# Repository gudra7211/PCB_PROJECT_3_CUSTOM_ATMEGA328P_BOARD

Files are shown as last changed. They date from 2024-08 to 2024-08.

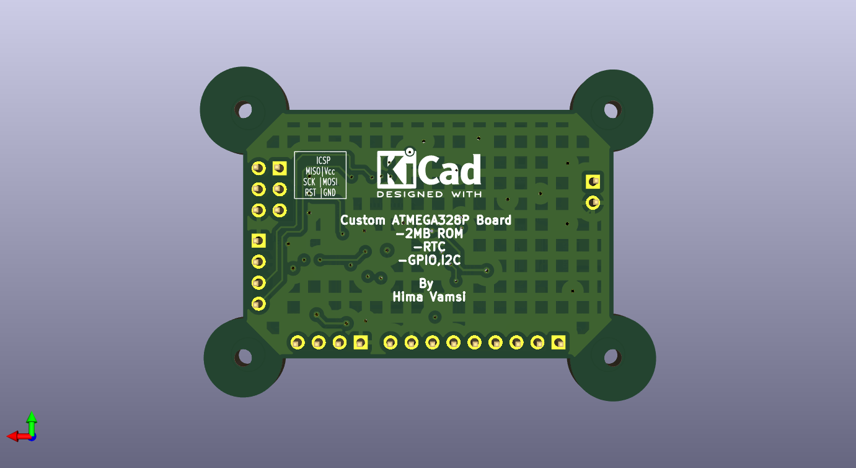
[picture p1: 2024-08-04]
Bottom_View_4Layer_Data_Logger.png

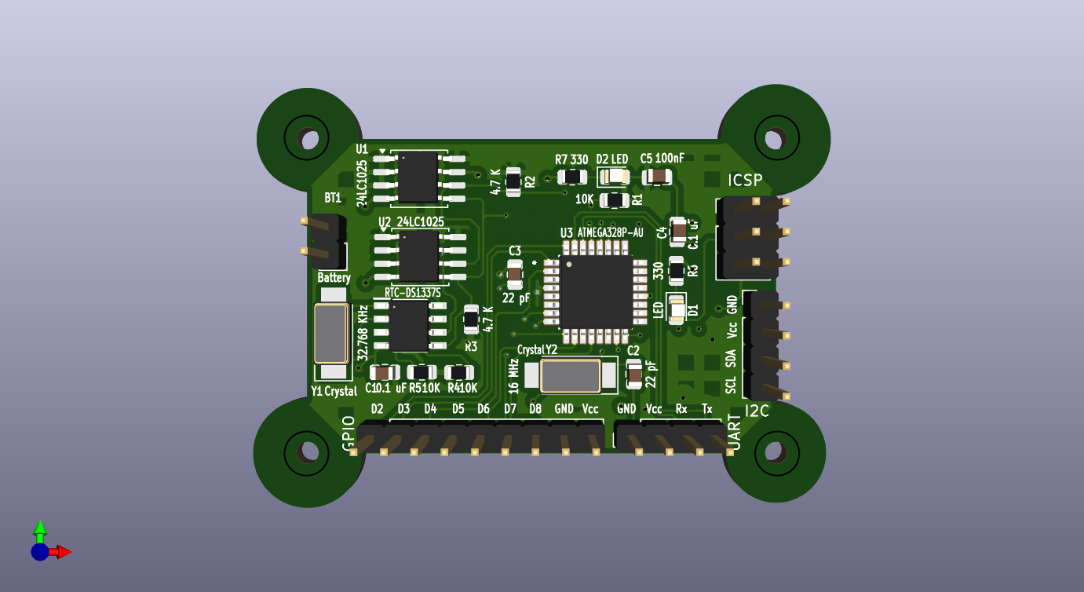
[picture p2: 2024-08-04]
Top_View_4Layer_Data_Logger.png

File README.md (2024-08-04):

# PCB_PROJECT_3_CUSTOM_ATMEGA328P_BOARD

You are in the 4layer branch of this repo. Here you can find the project files related to 4layer design. Here I utilized copper fills and I recommend using copper fills as it gives more spac for routing other components.

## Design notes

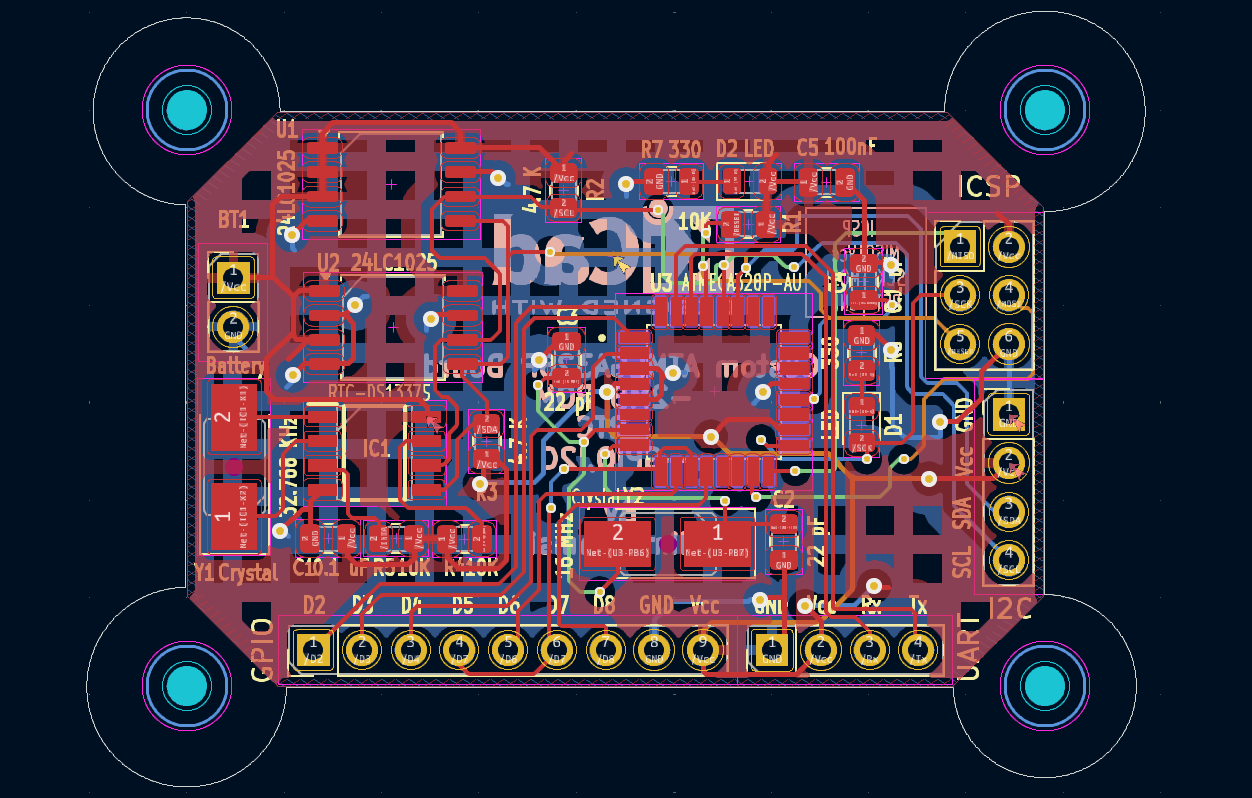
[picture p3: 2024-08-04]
PCB-Editor-MCU_DATA_LOGGER_4LAYER.png

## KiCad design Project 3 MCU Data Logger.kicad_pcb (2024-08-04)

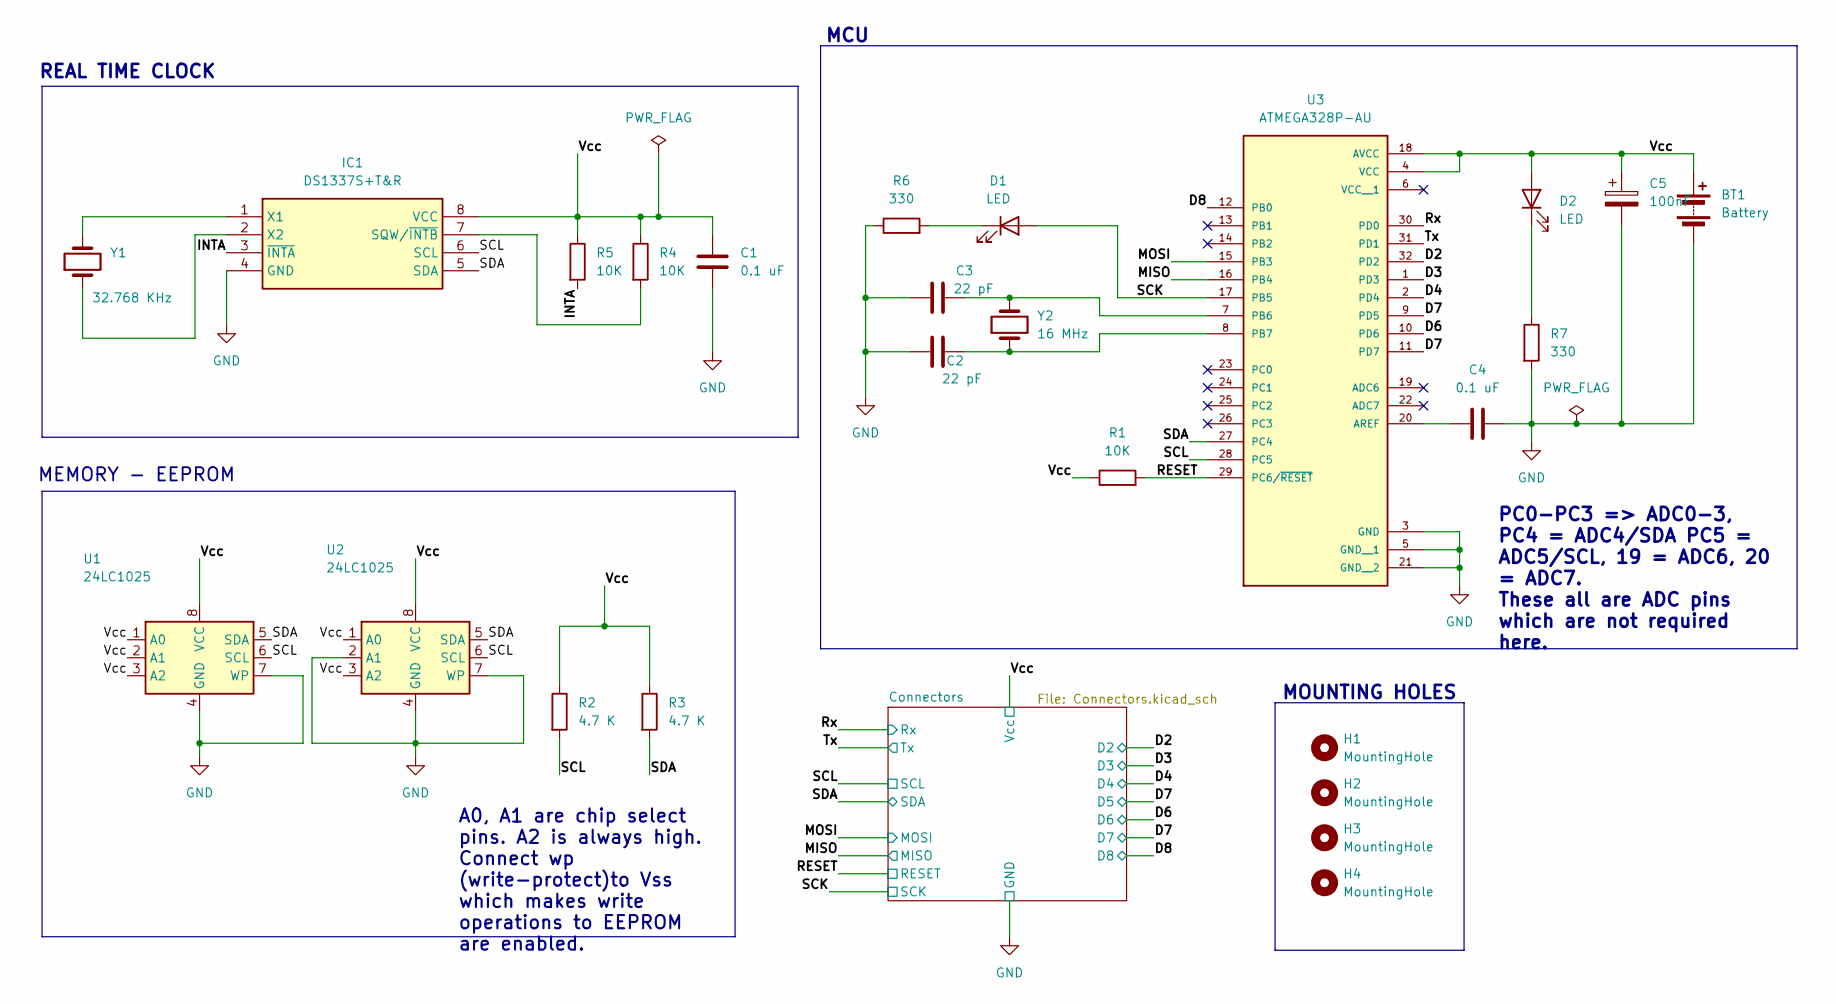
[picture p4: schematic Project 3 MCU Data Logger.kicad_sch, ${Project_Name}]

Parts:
BT1: Battery; PinHeader_1x02_P2.54mm_Vertical
C1, C4: 0.1 uF; C_0805_2012Metric
C2, C3: 22 pF; C_0805_2012Metric
C5: 100nF; C_0805_2012Metric
D1, D2: LED; LED_0805_2012Metric
H1, H2, H3, H4: MountingHole; MountingHole_2.1mm
IC1: DS1337S+T&R; SOIC127P600X175-8N; Manufacturer_Part_Number DS1337S+T&R; Mouser Part Number 700-DS1337ST&R
R1, R4, R5: 10K; R_0805_2012Metric
R2, R3: 4.7 K; R_0805_2012Metric
R6, R7: 330; R_0805_2012Metric
U1, U2: 24LC1025; SOIC-8_5.23x5.23mm_P1.27mm
U3: ATMEGA328P-AU; QFP80P900X900X120-32N; PARTREV 8271A
Y1: 32.768 KHz; Crystal_SMD_5032-2Pin_5.0x3.2mm_HandSoldering
Y2: 16 MHz; Crystal_SMD_5032-2Pin_5.0x3.2mm_HandSoldering

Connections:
/D2: U3.32 (PD2); also elsewhere on the board
/D3: U3.1 (PD3); also elsewhere on the board
/D4: U3.2 (PD4); also elsewhere on the board
/D6: U3.10 (PD6); also elsewhere on the board
/D7: U3.9 (PD5), U3.11 (PD7); also elsewhere on the board
/D8: U3.12 (PB0); also elsewhere on the board
/INTA: IC1.3 (~INTA), R5.2
/MISO: U3.16 (PB4); also elsewhere on the board
/MOSI: U3.15 (PB3); also elsewhere on the board
/RESET: R1.2, U3.29 (PC6/~RESET); also elsewhere on the board
/Rx: U3.30 (PD0); also elsewhere on the board
/SCK: D1.2 (A), U3.17 (PB5); also elsewhere on the board
/SCL: IC1.6 (SCL), R2.2, U1.6 (SCL), U2.6 (SCL), U3.28 (PC5); also elsewhere on the board
/SDA: IC1.5 (SDA), R3.2, U1.5 (SDA), U2.5 (SDA), U3.27 (PC4); also elsewhere on the board
/Tx: U3.31 (PD1); also elsewhere on the board
/Vcc: BT1.1 (+), C1.1, C5.1, D2.2 (A), IC1.8 (VCC), R1.1, R2.1, R3.1, R4.1, R5.1, U1.1 (A0), U1.2 (A1), U1.3 (A2), U1.8 (VCC), U2.1 (A0), U2.3 (A2), U2.8 (VCC), U3.4 (VCC), U3.18 (AVCC); also elsewhere on the board
GND: BT1.2 (-), C1.2, C2.1, C3.1, C4.2, C5.2, IC1.4 (GND), R6.1, R7.2, U1.4 (GND), U1.7 (WP), U2.2 (A1), U2.4 (GND), U2.7 (WP), U3.3 (GND), U3.5 (GND__1), U3.21 (GND__2); also elsewhere on the board
unnamed: D1.1 (K), R6.2
unnamed: D2.1 (K), R7.1
unnamed: IC1.7 (SQW/~INTB), R4.2
unnamed: IC1.1 (X1), Y1.2
unnamed: IC1.2 (X2), Y1.1
unnamed: C4.1, U3.20 (AREF)
unnamed: C3.2, U3.7 (PB6), Y2.2
unnamed: C2.2, U3.8 (PB7), Y2.1

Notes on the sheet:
PC0-PC3 => ADC0-3, PC4 = ADC4/SDA PC5 = ADC5/SCL, 19 = ADC6, 20 = ADC7. These all are ADC pins which are not required here.
A0, A1 are chip select pins. A2 is always high. Connect wp (write-protect)to Vss which makes write operations to EEPROM are enabled.
MOUNTING HOLES
MCU
MEMORY - EEPROM
REAL TIME CLOCK

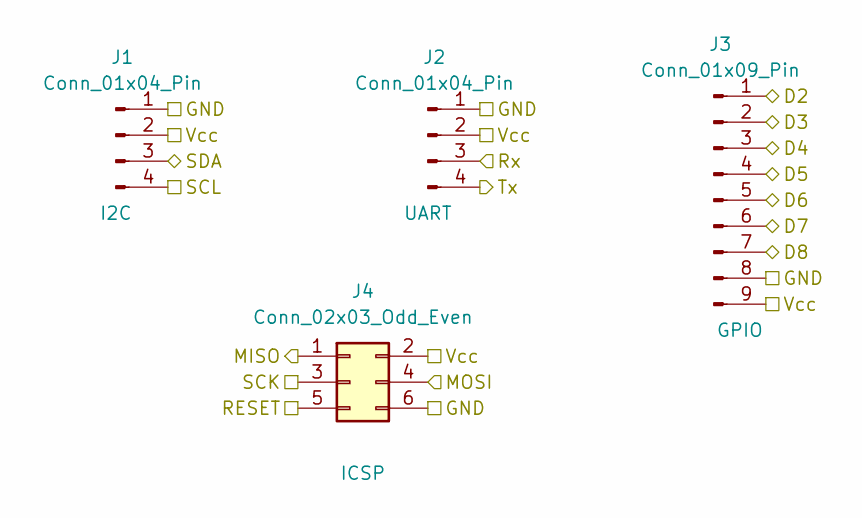
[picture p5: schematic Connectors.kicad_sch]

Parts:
J1, J2: Conn_01x04_Pin; PinHeader_1x04_P2.54mm_Vertical
J3: Conn_01x09_Pin; PinHeader_1x09_P2.54mm_Vertical
J4: Conn_02x03_Odd_Even; PinHeader_2x03_P2.54mm_Vertical

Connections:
/D2: J3.1; also elsewhere on the board
/D3: J3.2; also elsewhere on the board
/D4: J3.3; also elsewhere on the board
/D6: J3.5; also elsewhere on the board
/D7: J3.4, J3.6; also elsewhere on the board
/D8: J3.7; also elsewhere on the board
/MISO: J4.1; also elsewhere on the board
/MOSI: J4.4; also elsewhere on the board
/RESET: J4.5; also elsewhere on the board
/Rx: J2.3; also elsewhere on the board
/SCK: J4.3; also elsewhere on the board
/SCL: J1.4; also elsewhere on the board
/SDA: J1.3; also elsewhere on the board
/Tx: J2.4; also elsewhere on the board
/Vcc: J1.2, J2.2, J3.9, J4.2; also elsewhere on the board
GND: J1.1, J2.1, J3.8, J4.6; also elsewhere on the board

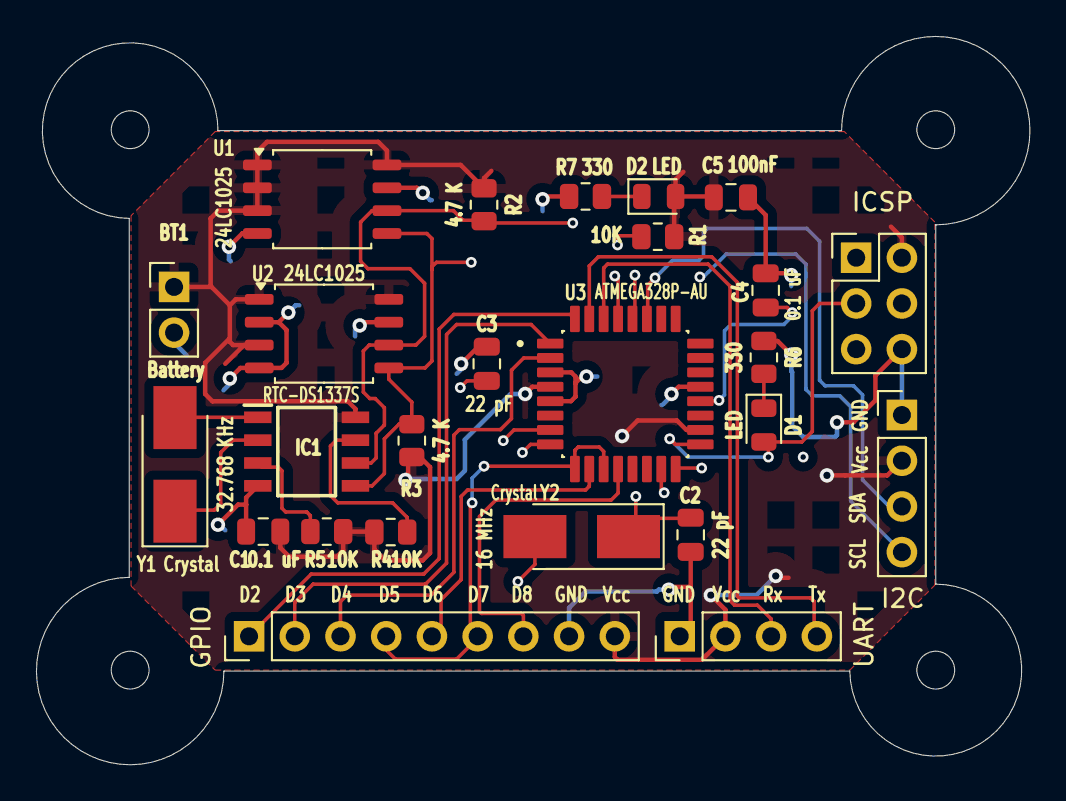
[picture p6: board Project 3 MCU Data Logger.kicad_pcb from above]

Board: 4 copper layers, 55.2 x 40.5 mm, 29 parts (0 on the bottom side), 25 nets.
